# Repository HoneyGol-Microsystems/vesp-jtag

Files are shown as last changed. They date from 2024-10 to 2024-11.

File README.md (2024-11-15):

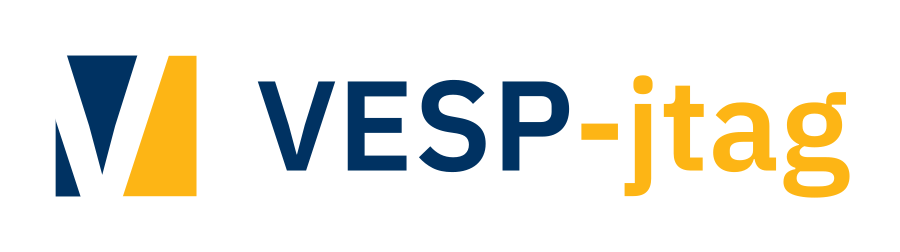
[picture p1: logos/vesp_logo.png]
vesp-jtag logo
# 
An Open Source Hardware JTAG/UART/GPIO interface board based on the amazing [Steppenprobe](https://github.com/diegoherranz/steppenprobe) containing Pmod-compatible connector.

## Basic specs:

- Open Source Hardware and designed in [KiCad](https://kicad.org).
- Majority of footprints have easy to solder 0805 packages.
- [FT2232H](https://ftdichip.com/products/ft2232hl)-based.
- Simultaneous operation of JTAG/UART or GPIO/UART (software-configurable).
- Standard Pmod connector for direct connection to a compatible FPGA.
- Signals also available on 2.54 mm pin header to work with any custom pinout.
- USB powered: no power supply needed.
- USB type-C receptacle: more convenient (reversible) and future-proof.
- 2 GPIO and 2 user-controllable LEDs.
- I/O buffers for protection and compatible with a wide voltage range (1.65 V to 5.5 V).
- Descriptive LED indicators.
- (TODO) OpenOCD compatibility.

*Please note that the board itself is wider than the Pmod standard allows, therefore it is not entirely "Pmod compatible". It may happen that if Pmod ports on your FPGA board are too close to each other, another Pmod board will not fit next to the vesp-jtag at the same time.*

## Schematic PDF, Gerbers and other generated files:
See [releases](https://github.com/HoneyGol-Microsystems/vesp-jtag/releases).

## FTDI channels

The FT2232H has 2 independent channels. In this board:

- Channel A: Used as a JTAG or GPIOs
- Channel B: Used as an UART.

After enumeration, both channels will default to the UART mode, so on a Linux system they will show up as `/dev/ttyUSB0` and `/dev/ttyUSB1`. When the channel A gets reconfigured to a MPSSE mode (e.g. when using OpenOCD with it), then `/dev/ttyUSB0` will disappear and the channel B will remain as `/dev/ttyUSB1`.

## 3D renders

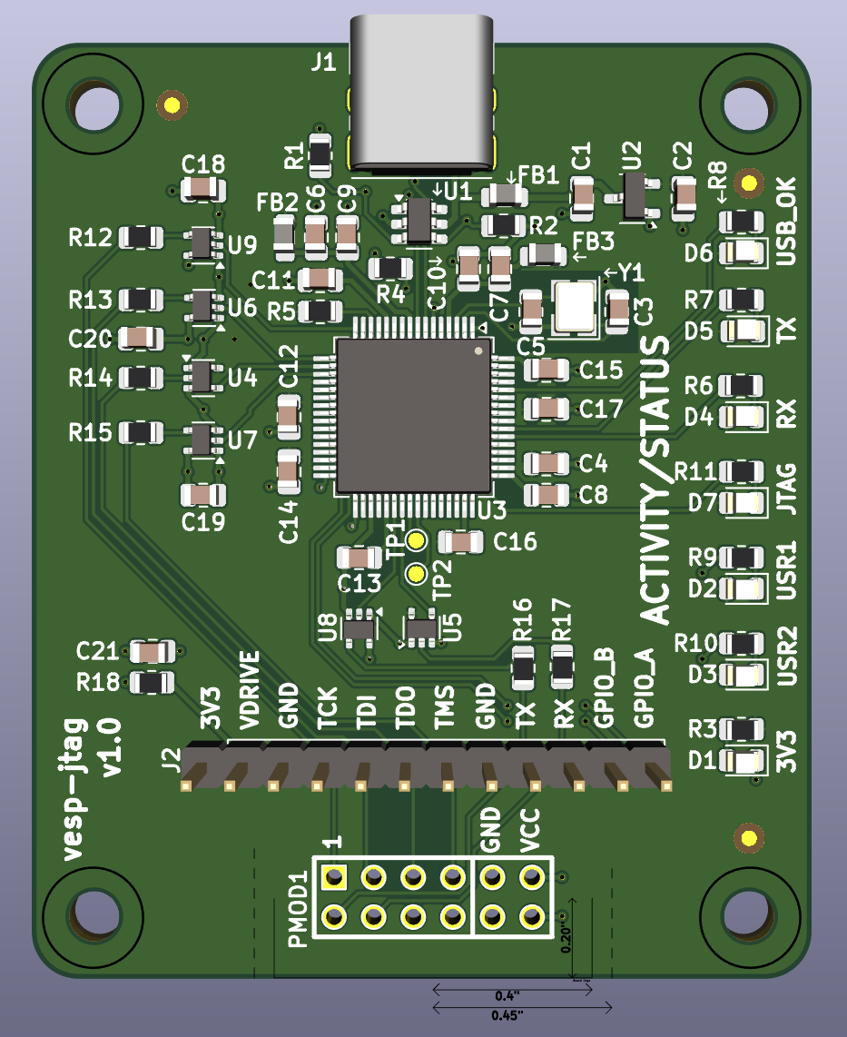
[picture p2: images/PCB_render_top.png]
PCB top view
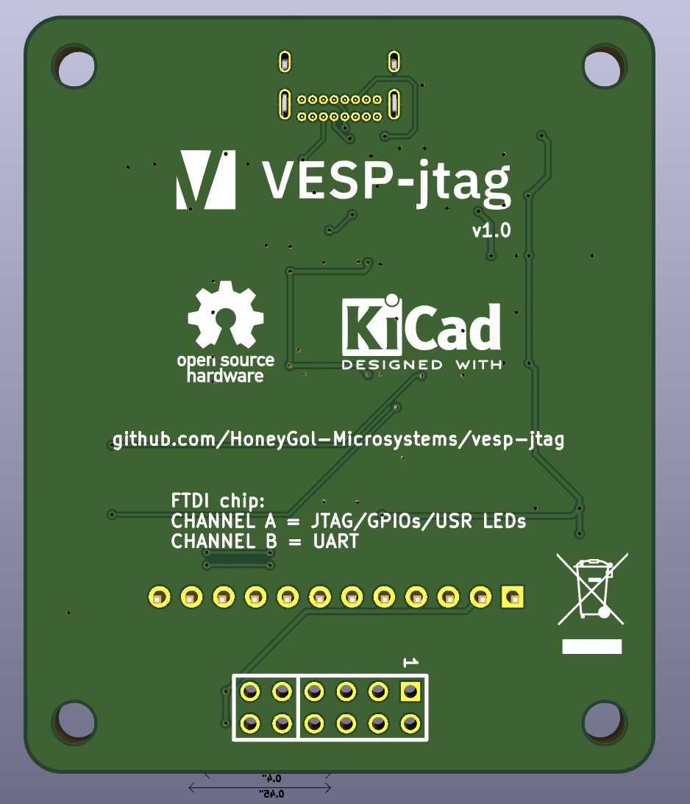
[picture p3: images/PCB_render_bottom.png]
PCB bottom view
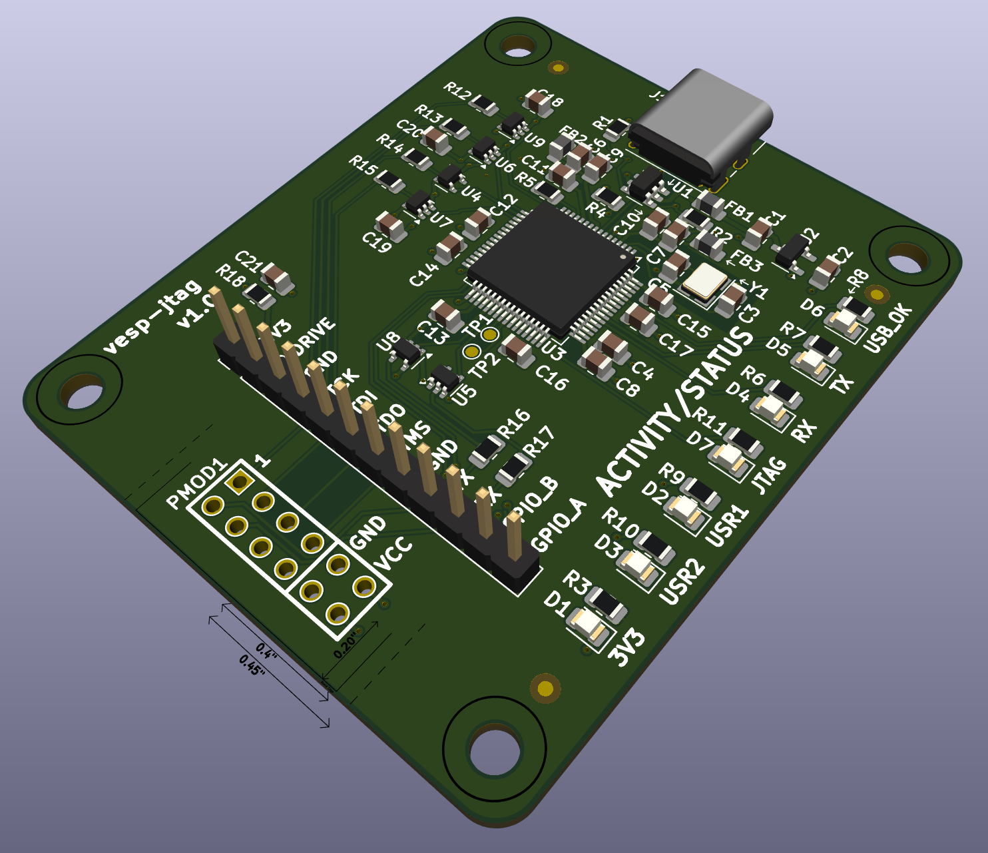
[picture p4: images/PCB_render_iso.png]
PCB isometric view
  

## OpenOCD example commands
TODO

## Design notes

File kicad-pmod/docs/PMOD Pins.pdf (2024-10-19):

PMod Interface | I2C Interface
Single Width PMod | Double Width PMod
Host | Edge | Peripheral 1 | 1 Host | 7 | Edge | Peripheral 1 7 | 1 | Edge
2 | | | 2 | 2 | 8 | | | 8 | 2 | 1 | 2 | SCL | SCL
3 | | | 3 | 3 | 9 | | | 9 | 3 | 3 | 4 | SDA | SDA
4 | | | 4 | 4 | 10 | | | 10 | 4 | 5 | 6 | GND | GND
5 | | | 5 | 5 | 11 | | | 11 | 5 | 7 | 8 | VCC | VCC
6 | | | 6 | 6 | 12 | | | 12 | 6
| 0.40" | 0.15" | | Top | Bot | 0.45" | 0.20" | Bot | Top

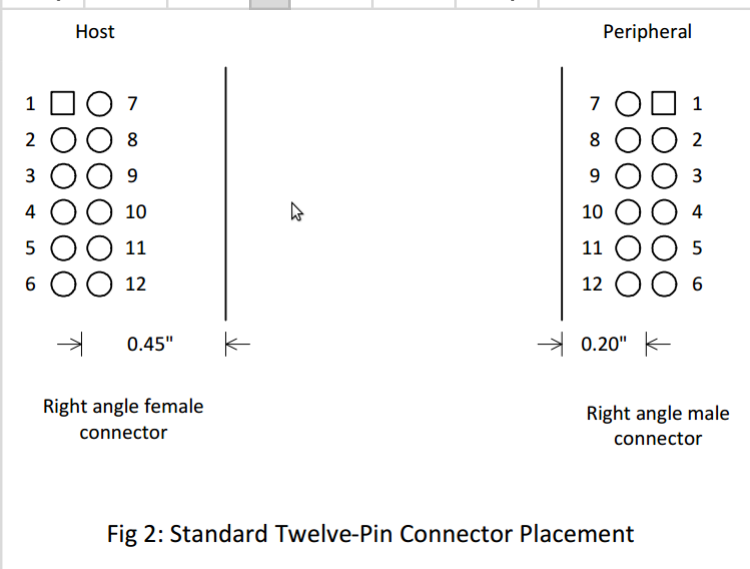
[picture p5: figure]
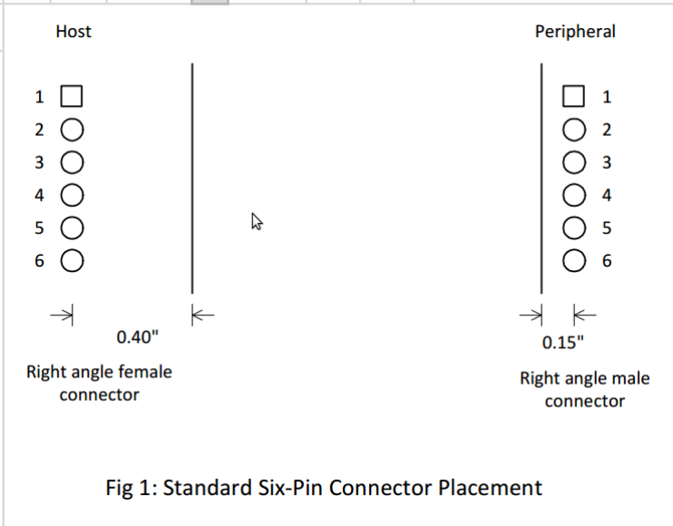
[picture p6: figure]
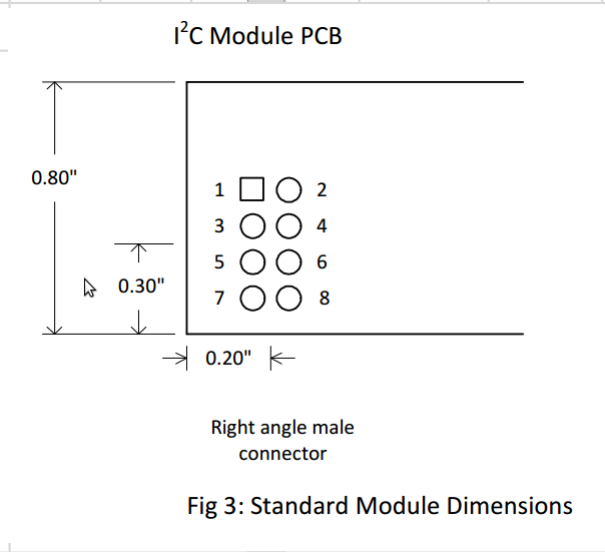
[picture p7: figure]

Pmod Pin | Standard Pin | | | Standard Pins | | Pmod Pins
1 | 2 | IO | Edge | 1 | 2 | Edge | 7 | 1
2 | 4 | IO | | 3 | 4 | | 8 | 2
3 | 6 | IO | | 5 | 6 | | 9 | 3
4 | 8 | IO | | 7 | 8 | | 10 | 4
5 | 10 | GND | | 9 | 10 | | 11 | 5
6 | 12 | VCC | | 11 | 12 | | 12 | 6
7 | 1 | IO
8 | 3 | IO
9 | 5 | IO
10 | 7 | IO
11 | 9 | GND
12 | 11 | VCC
Pmod Pin | Standard Pin | | | Standard Pins | | Pmod Pins
1 | 11 | IO | Edge | 12 | 11 | Edge | 7 | 1
2 | 9 | IO | | 10 | 9 | | 8 | 2
3 | 7 | IO | | 8 | 7 | | 9 | 3
4 | 5 | IO | | 6 | 5 | | 10 | 4
5 | 3 | GND | | 4 | 3 | | 11 | 5
6 | 1 | VCC | | 2 | 1 | | 12 | 6
7 | 12 | IO 8 | 10 | IO 9 | 8 | IO
10 | 6 | IO
11 | 4 | GND
12 | 2 | VCC

Type 1 GPIO | Type 1A Expanded GPIO | Type 2 SPI | Type 2A Expanded SPI | Type 3 UART | Type 4 UART | Type 4A Expanded UART | Type 5 H-Bridge | Type 6 Dual H-Bridge
1 2 3 4 | IO1 IO2 IO3 IO4 | In/Out In/Out In/Out In/Out | 1 2 3 4 | IOA1 IOA2 IOA3 IOA4 | In/Out In/Out In/Out In/Out | 1 2 3 4 | SS MOSI MISO SCK | Out Out | 1 2 | SS MOSI | Out Out | 1 2 | CTS RTS | Out | 1 | CTS | In | 1 | CTS | In | 1 DIR | Out | 1 DIR1 | Out
| | | | | | | | | | | | | | In | 2 | TXD | Out | 2 | TXD | Out | 2 EN | Out | 2 EN1 | Out
| | | | | | | | In | 3 | MISO | In | 3 | RXD | In | 3 | RXD | In | 3 | RXD | In | 3 SA | In | 3 DIR2 | Out
| | | | | | | | Out | 4 | SCK | Out | 4 | TXD | Out | 4 | RTS | Out | 4 | RTS | Out | 4 SB | In | 4 EN2 | Out
5 | GND | | 5 | GND | | 5 | GND | | 5 | GND | | 5 | GND | | 5 | GND | | 5 | GND | | 5 GND | | 5 GND
6 | VCC | | 6 | VCC | | 6 | VCC | | 6 | VCC | | 6 | VCC | | 6 | VCC | | 6 | VCC | | 6 VCC | | 6 VCC
| | | 7 8 9 10 | IOB1 IOB2 IOB3 IOB4 | In/Out In/Out In/Out In/Out | | | | 7 8 9 10 | INT RESET N/S N/S | In | | | | | | | 7 | INT | In
| | | | | | | | | | | Out | | | | | | | 8 | RESET | Out
| | | | | | | | | | | N/S N/S | | | | | | | 9 10 | N/S N/S | N/S N/S
| | | 11 | GND | | | | | 11 | GND | | | | | | | | 11 | GND
| | | 12 | VCC | | | | | 12 | VCC | | | | | | | | 12 | VCC
| | | | | | SS - Slave Select. Active low to enable slave device slave to master SCK - Serial clock. Data clock from master to slave | | | | | | CTS - Permission for peripheral to send data to host RTS - Request from peripheral to send data to host RXD - Data from peripheral to host | | | CTS - Device will only transmit when this signal is asserted RTS - Device is ready to receive data RXD - Data from peripheral to host TXD - Data from host to peripheral | | | CTS - Device will only transmit when this signal is asserted RTS - Device is ready to receive data RXD - Data from peripheral to host TXD - Data from host to peripheral INT - Interrupt signal from peripheral to host RESET - Reset signal for host to reset peripheral N/S - Not-specified depending on the module these pins may be unconnected or additional module specific inputs or outputs. | | | DIR - Motor direction EN - Motor enable, active high SA - feedback sense A SB - feedback sense B | | DIR1 - Motor/Phase 1 direction, active high MOSI - Master Out Slave In. Data from master to slave EN1 - Motor/Phase 1 enable MISO - Master In Slave Out. Data from DIR2 - Motor/Phase 2 direction, active high EN2 - Motor/Phase 2 enable
Pin | Signal | Direction | Pin | Signal | Direction | Pin | Signal | Direction | Pin | Signal | Direction | Pin | Signal | Direction | Pin | Signal | Direction | Pin | Signal | Direction | Pin | Signal | Direction | Pin | Signal | Direction

Pmod "High Speed" | XADC Pmod | Low Speed
Pin | Signal | LVDS Pair | Pin | Signal | LVDS Pair | Pin | Signal | LVDS Pair
1 | JA1_P | JA1 | 1 | JA1_P | JA1 | 1 | IO1 | NA
2 | JA1_N | | 2 | JA2_P | JA2 | 2 | IO2
3 | JA2_P | JA2 | 3 | JA3_P | JA3 | 3 | IO3
4 | JA2_N | | 4 | JA4_P | JA4 | 4 | IO4
5 | GND | | 5 | GND | | 5 | GND
6 | VCC | | 6 | VCC | | 6 | VCC
7 | JA3_P | JA3 | 7 | JA1_N | JA1 | 7 | IO1
| JA3_N | | 8 | JA2_N | JA2 | 8 | IO2 | NA 8
9 | JA4_P | JA4 | 9 | JA3_N | JA3 | 9 | IO3
10 | JA4_N | | 10 | JA4_N | JA4 | 10 | IO4
11 | GND | | 11 | GND | | 11 | GND
12 | VCC | | 12 | VCC | | 12 | VCC
* 0 Ohm series resistor * ESD protection | | | * No series resistor * ESD protection | | | * ~200 Ohm series resistor * Sometimes ESD protection
TMDS_33 input + output | ~XADC Pmod | | LVDS_25 input/output
LVDS_25 input | | Pin | Signal | LVDS Pair
1 | JA1_N | JA1
2 | JA2_N | JA2
3 | JA3_N | JA3
4 | JA4_N | JA4
5 | GND
6 | VCC
7 | JA1_P | JA1
8 | JA2_P | JA2
9 | JA3_P | JA3
10 | JA4_P | JA4
11 | GND
12 | VCC

Digilent Arty (https://reference.digilentinc.com/_media/arty:arty_sch.pdf) | Artix 7 | 100E
JA | Low Speed
| High Speed | Group 1 JB | No ESD?, JB1 - SRCC, JB2 - MRCC
JC | High Speed | | No ESD?
JD | Low Speed | | Uses mostly clock pins
Digilent Nexys Video (https://reference.digilentinc.com/_media/nexys-video:nexys_video_sch.pdf) | Artix 7 | GigE, HDMI In, HDMI Out, DP Out -- FMC(2 x HDMI In)
JA | Low Speed | Group 1
JB | High Speed | Group 2
JC | High Speed
JXADC XADC | | Group 3 | 100 Ohm Resistor
Digilent Nexys 4 DDR (https://reference.digilentinc.com/_media/nexys4-ddr:nexys_4_ddr_sch.pdf) | Artix 7
JA | Low Speed
JB | Low Speed
JC | Low Speed
JD | Low Speed
JXADC XADC
Digilent Genesys 2 (https://reference.digilentinc.com/_media/genesys2:genesys2_public_sch.pdf) | Kintex 7 | GigE, HDMI In, HDMI Out, DP In, DP Out, VGA Out -- FMC(2 x HDMI In)
JA | High Speed | Group 1
JB | High Speed
JC | Low Speed | Group 2
JD | Low Speed
JXADC XADC | | Group 3
Digilent Zybo (https://reference.digilentinc.com/_media/zybo:zybo_sch.pdf) | Zynq | GigE, HDMI BiDir, VGA Out
JA | XADC | Group 1
JB | High Speed
| High Speed | Group 2 JC
JD | High Speed | | JD3 - SRCC
JE | Low Speed
JF | Low Speed | Group 3 | MIO PMOD?
ZedBoard (https://reference.digilentinc.com/_media/reference/programmable-logic/zedboard/zedboard_sch.pdf) Zynq | | GigE, HDMI Out, VGA Out
JA1 | Low Speed | Group 1
JB1 | Low Speed

JC1 | High Speed | Group 2
JD1 | High Speed
JE1 | Low Speed | MIO PMOD?
Digilent PYNQ (https://reference.digilentinc.com/_media/reference/programmable-logic/pynq-z1/pynq-z1_sch.pdf) | Zynq | GigE, HDMI In, HDMI Out
PMODA | High Speed | Group 1 | 200 Ohm Resistor, JA3 - MRCC
PMODB | High Speed | | 200 Ohm Resistor
TOFE LowSpeedIO (https://github.com/timvideos/HDMI2USB-TOFE-LowSpeedIO/raw/master/docs/TOFE-LowSpeedIO-v1.0.0-4-g63ba16f.pdf) | | | Check Spacing
P2 | XADC | Group 1
P1 | XADC
P4 | Low Speed
P3 | Low Speed | Group 2
Numato Mimas V2 (https://docs.numato.com/wp-content/uploads/2016/08/MimasV2Sch.pdf) | Spartan 6 | | Check Spacing
P6 | ~XADC
P7 | ~XADC
P8 | ~XADC
P9 | ~XADC
Numato Waxwing (https://docs.numato.com/wp-content/uploads/2016/08/WaxwingBasicDevelopmentBoardSch.pdf) | Spartan 6 | | Check Spacing
P3 | XADC
P5 | XADC
P4 | XADC
MicroZed (http://zedboard.org/sites/default/files/documentations/MicroZed_Rev_F_Schematic_141212.pdf) | Zynq
J5 | | | MIO PMOD???

MyIRTech Z-turn with IO CapeZynq XADC?
PMOD1?
PMOD2?
PMOD3?
Pipistrello (http://www.saanlima.com/download/pipistrello-v2.0/pipistrello_v2_schematic.pdf) | Spartan 6
PMOD | Low Speed | | No resistors or ESD
icoBoard (http://downloads.amescon.com/icoboard.pdf) | Lattice??
P1 | Low Speed | | Check
P3 | Low Speed | | Check

P2 | Low Speed | Check
P4 | Low Speed | Check

| Numato | | | Numato | | | Numato | | | Numato | | | Numato | | | Digilent
HDMI Transmitter
Expansion Module

RTL8211E Gigabit Ethernet
Expansion Module | FT234 Expansion Module | VGA Display Expansion Module | Micro SD Expansion Module | Pmod SD: Full-sized SD Card Slot
http://numato.com/hdmi-transmitter-expansion-module/ http://numato.com/rtl8211e-gigabit-ethernet-expansion-module/ http://numato.com/ft234-expansion-module/ | http://numato.com/vga-display-expansion-module/ | http://numato.com/micro-sd-expansion-module/http://store.digilentinc.com/pmod-sd-full-sized-sd-card-slot/
2 x Dual PMOD | 3 x Dual PMOD | 1 x Dual PMOD | 2 x Dual PMOD | 1 x Dual PMOD | 1 x Dual PMOD
Module | ~XADC | P1 | Module | Low Speed | P1 | Module | Low Speed | P1 | Module | Low Speed | P1 | Module | Low Speed | P1 | Module | Low Speed | P1
PMod
Pin | Signal | Numato
| | Pin | PMod
| | | Pin | Signal | Numato
| | | | | Pin | PMod
| | | | | | Pin | Signal | Numato
| | | | | | | | Pin | PMod
| | | | | | | | | Pin | Signal | Numato
| | | | | | | | | | | Pin | PMod
| | | | | | | | | | | | Pin | Signal | Numato
| | | | | | | | | | | | | | Pin | PMod
| | | | | | | | | | | | | | | Pin | Signal | Direction
1 2 3 4 5 6 7 8 9 10 11 12 Module PMod Pin | TMDS-TX-2_P TMDS-TX-1_P TMDS-TX-0_P TMDS-TX-CLK_P GND VCC TMDS-TX-2_N TMDS-TX-1_N TMDS-TX-0_N TMDS-TX-CLK_N GND VCC Low Speed Signal | 2 4 6 8 10 12 1 3 5 7 9 11 P2 Numato Pin | 1 2 3 4 5 6 7 8 9 10 11 12 Module PMod Pin | NC ETH_RXCTL ETH_RXD1 ETH_RXD3 GND VCC NC ETH_RXD0 ETH_RXD2 ETH_INT_B GND VCC Low Speed Signal | 2 4 6 8 10 12 1 3 5 7 9 11 P2 Numato Pin | 1 2 3 4 5 6 7 8 9 10 11 12 | CBUS0 NC NC NC GND VCC TXD RTS RXD CTS GND VCC | 2 4 6 8 10 12 1 3 5 7 9 11 | 1 R1 2 2 G2 4 3 G1 6 4 B1 8 5 GND 10 6 VCC 12 7 R2 1 8 R0 3 9 G0 5 10 B0 7 11 GND 9 12 VCC 11 Module Low Speed P2 PMod Numato Pin Signal Pin | 1 DAT2 2 2 CMD 4 3 DAT0 6 4 NC 8 5 GND 10 6 VCC 12 7 DAT3 1 8 CLK 3 9 DAT1 5 10 NC 7 11 GND 9 12 VCC 11 | 1 SS Out 2 MOSI Out 3 MISO In 4 SCK Out 5 GND 6 VCC 7 DAT1 8 DAT2 9 CD 10 WP 11 GND 12 VCC
1 2 3 4 5 6 7 8 9 10 11 12 | TMDS-TX-SCL TMDS-TX-HOT NC NC GND VCC TMDS-TX-CEC TMDS-TX-SDA NC NC GND VCC | 2 4 6 8 10 12 1 3 5 7 9 11 | 1 2 3 4 5 6 7 8 9 10 11 12 Module PMod Pin | NC ETH_TXCLK ETH_TXD1 ETH_TXD3 GND VCC NC ETH_RXCLK ETH_TXD0 ETH_TXD2 GND VCC Low Speed Signal | 2 4 6 8 10 12 1 3 5 7 9 11 P3 Numato Pin | | | | 1 Vsync 2 2 NC 4 3 NC 6 4 NC 8 5 GND 10 6 VCC 12 7 Hsync 1 8 NC 3 9 NC 5 10 NC 7 11 GND 9 12 VCC 11
1 | ETH_RESET_B | 2
2 | ETH_MDIO | 4
3 | MAC_SDA | 6
4 | FPGA_CLK | 8
5 | GND | 10
6 | VCC | 12
7 | ETH_TXCTL | 1
8 | ETH_MDC | 3
9 | MAC_SCL | 5
10 | SYSCLK | 7
11 | GND | 9
12 | VCC | 11

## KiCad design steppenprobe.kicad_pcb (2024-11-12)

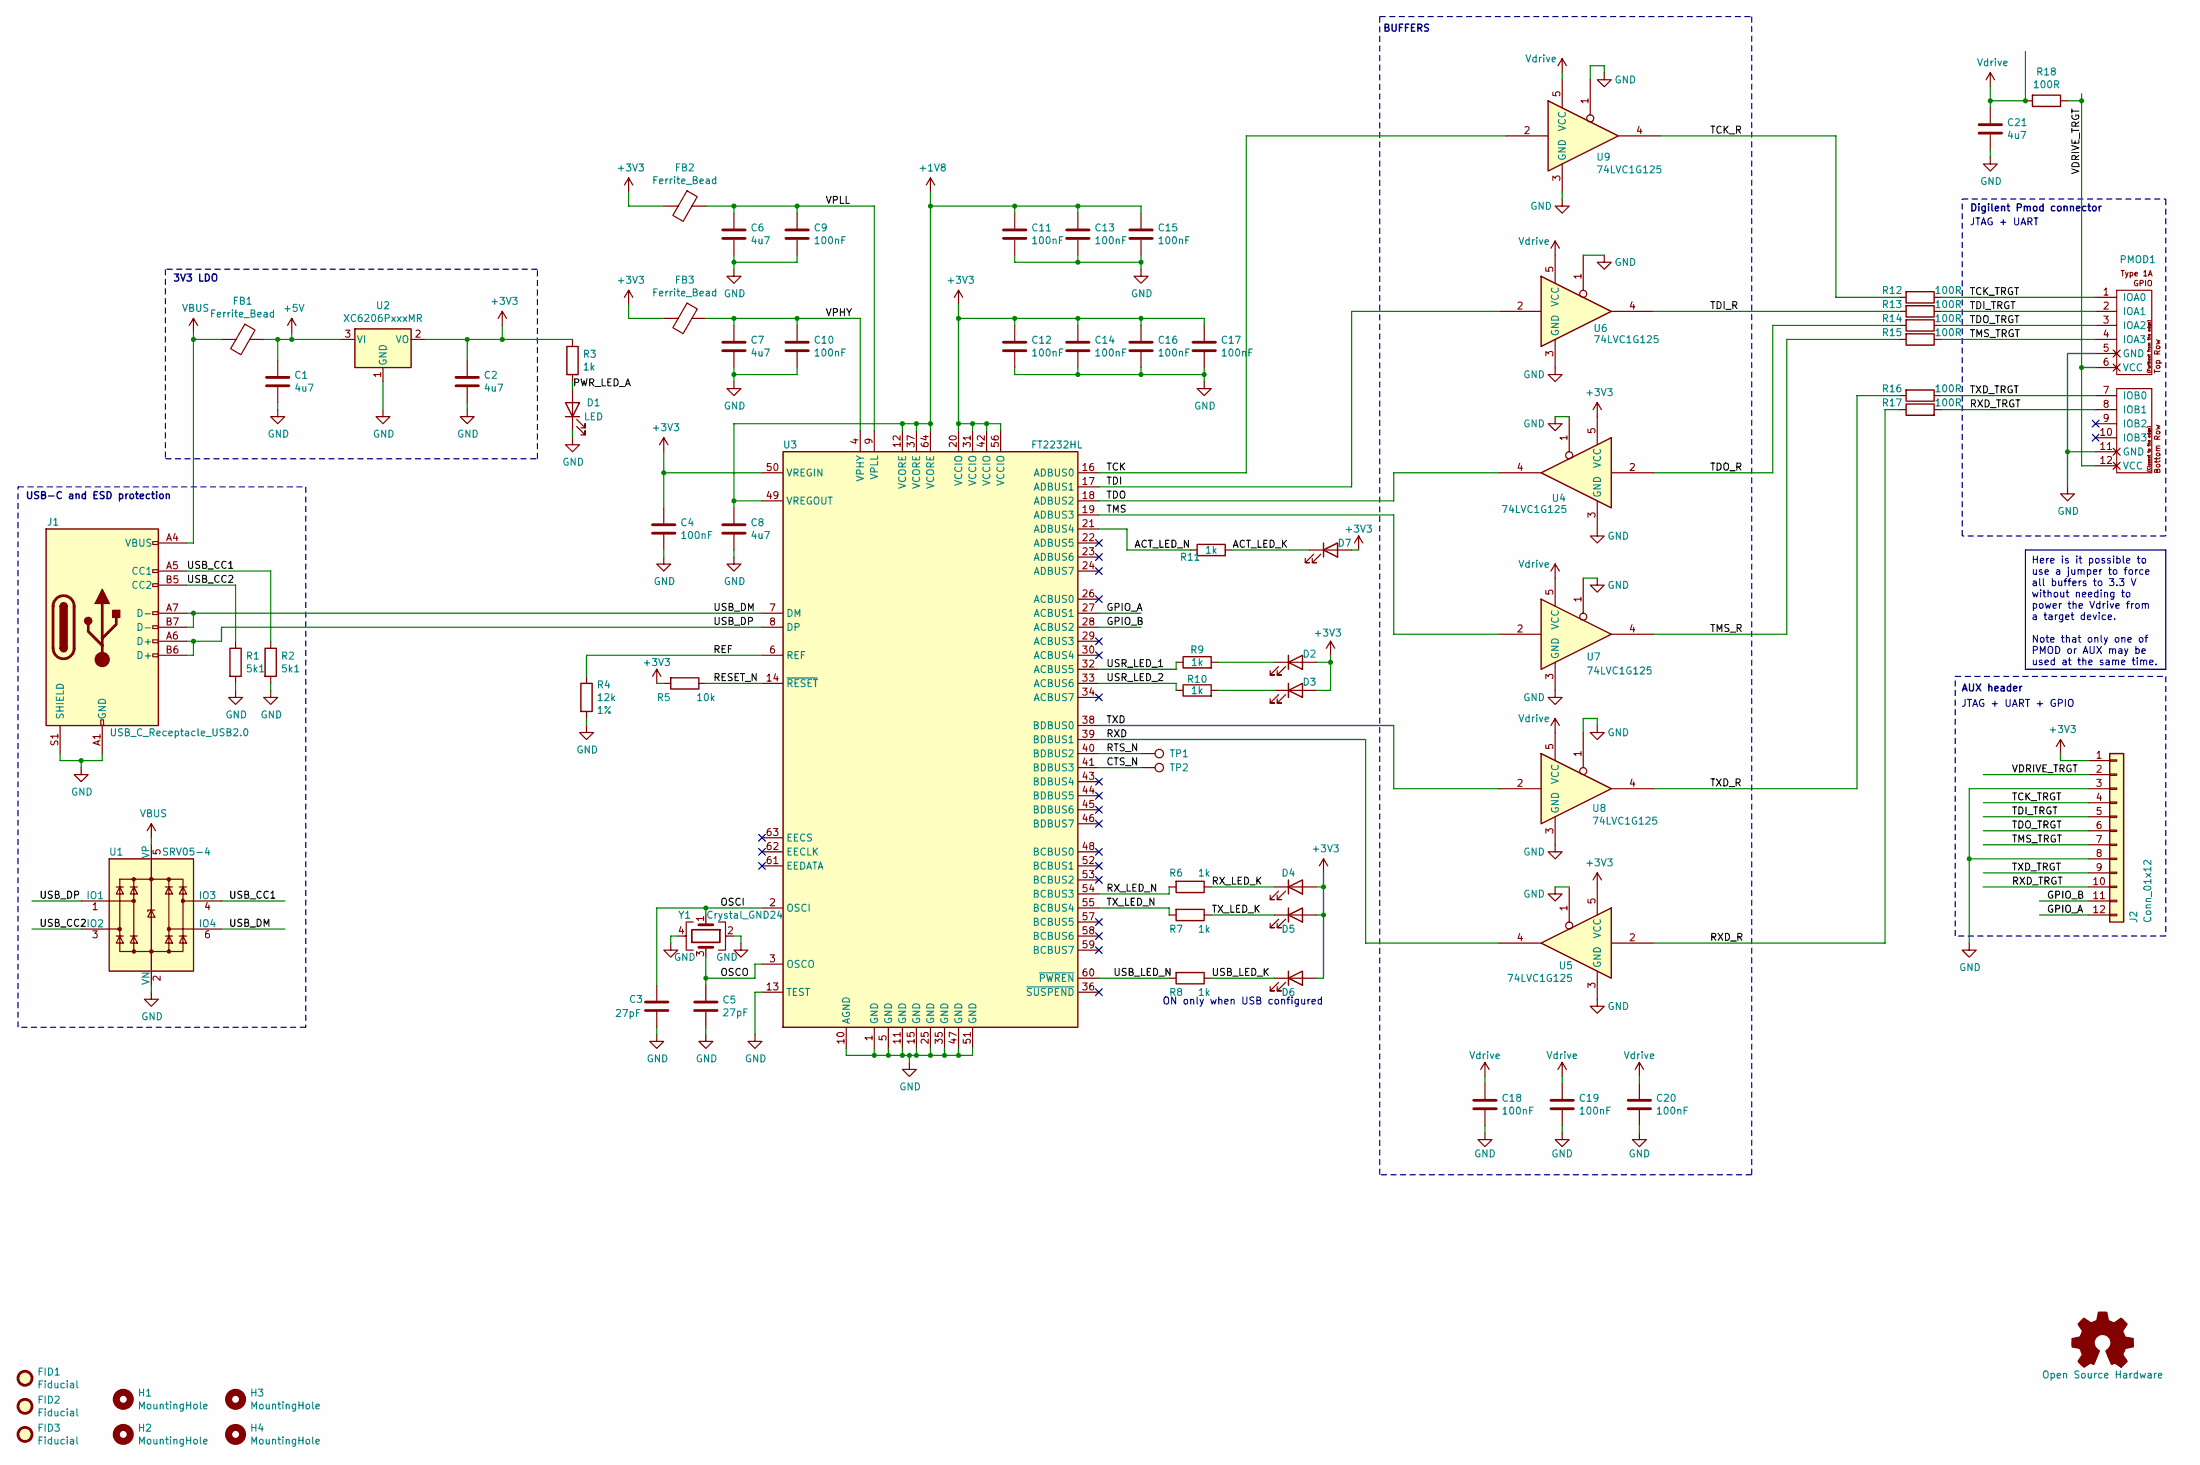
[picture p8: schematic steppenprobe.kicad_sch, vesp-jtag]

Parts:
C1, C2, C6, C7, C8, C21: 4u7; C_0805_2012Metric; Tolerance 10%; MPN CL10A475KO8NNNC; LCSC_PN C19666
C3, C5: 27pF; C_0805_2012Metric; Tolerance 5%; MPN C0603C270J5GAC; LCSC_PN C1656
C4, C9, C10, C11, C12, C13, C14, C15, C16, C17, C18, C19, C20: 100nF; C_0805_2012Metric; Tolerance 10%; MPN CC0603KRX7R9BB104; LCSC_PN C14663
D1, D4, D5, D6, D7: LED; LED_0805_2012Metric; MPN 19-217/GHC-YR1S2/3T; LCSC_PN C72043
D2, D3: LED; LED_0805_2012Metric
FB1, FB2, FB3: Ferrite_Bead; L_0805_2012Metric; MPN2 BKP1608HS121-T; LCSC_PN C85831
FID1, FID2, FID3: Fiducial; Fiducial_1mm_Mask2mm
H1, H2, H3, H4: MountingHole; MountingHole_3.2mm_M3
J1: USB_C_Receptacle_USB2.0; USB_C_Receptacle_GCT_USB4085; MPN USB4085-GF-A
J2: Conn_01x12; PinHeader_1x12_P2.54mm_Vertical
LOGO1: Open Source Hardware; OSHW-Logo_7.5x8mm_SilkScreen
PMOD1: PMOD-Device-x2-Type-1A-GPIO; pmod_pin_array_6x2
R1, R2: 5k1; R_0805_2012Metric; Tolerance 5%; LCSC_PN C23186
R3, R6, R7, R8, R11: 1k; R_0805_2012Metric; Tolerance 5%; LCSC_PN C21190
R4: 12k; R_0805_2012Metric; Tolerance 1%; LCSC_PN C22790
R5: 10k; R_0805_2012Metric; Tolerance 5%; LCSC_PN C25804
R9, R10: 1k; R_0805_2012Metric
R12, R13, R14, R15, R16, R17, R18: 100R; R_0805_2012Metric; Tolerance 5%; LCSC_PN C22775
TP1, TP2: TestPoint; TestPoint_Pad_D1.0mm
U1: SRV05-4; SOT-23-6; MPN2 SRV05-4-P-T7; LCSC_PN C85364
U2: XC6206PxxxMR; SOT-23-3; MPN XC6206P332MR; LCSC_PN C5446
U3: FT2232HL; LQFP-64_10x10mm_P0.5mm; MPN FT2232HL; LCSC_PN C27882
U4, U5, U6, U7, U8, U9: 74LVC1G125; SOT-353_SC-70-5; MPN 74LVC1G125GW,125; LCSC_PN C12519
Y1: Crystal_GND24; Crystal_SMD_3225-4Pin_3.2x2.5mm; Tolerance 10PPM; MPN ABM8-12.000MHZ-20-B1U-T; LCSC_PN C9002

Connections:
+1V8: C8.1, C11.1, C13.1, C15.1, U3.12 (VCORE), U3.37 (VCORE), U3.49 (VREGOUT), U3.64 (VCORE)
+3V3: C2.1, C4.1, C12.1, C14.1, C16.1, C17.1, D2.2 (A), D3.2 (A), D4.2 (A), D5.2 (A), D6.2 (A), D7.2 (A), FB2.2, FB3.2, J2.1, R3.1, R5.2, U2.2 (VO), U3.20 (VCCIO), U3.31 (VCCIO), U3.42 (VCCIO), U3.50 (VREGIN), U3.56 (VCCIO), U4.5 (VCC), U5.5 (VCC)
+5V: C1.1, FB1.1, U2.3 (VI)
/ACT_LED_K: D7.1 (K), R11.2
/ACT_LED_N: R11.1, U3.21 (ADBUS4)
/CTS_N: TP2.1, U3.41 (BDBUS3)
/GPIO_A: J2.12, U3.27 (ACBUS1)
/GPIO_B: J2.11, U3.28 (ACBUS2)
/OSCI: C3.1, U3.2 (OSCI), Y1.1
/OSCO: C5.1, U3.3 (OSCO), Y1.3
/PWR_LED_A: D1.2 (A), R3.2
/REF: R4.1, U3.6 (REF)
/RESET_N: R5.1, U3.14 (~RESET)
/RTS_N: TP1.1, U3.40 (BDBUS2)
/RXD: U3.39 (BDBUS1), U5.4
/RXD_R: R17.1, U5.2
/RXD_TRGT: J2.10, PMOD1.8 (IOB1), R17.2
/RX_LED_K: D4.1 (K), R6.1
/RX_LED_N: R6.2, U3.54 (BCBUS3)
/TCK: U3.16 (ADBUS0), U9.2
/TCK_R: R12.2, U9.4
/TCK_TRGT: J2.4, PMOD1.1 (IOA0), R12.1
/TDI: U3.17 (ADBUS1), U6.2
/TDI_R: R13.2, U6.4
/TDI_TRGT: J2.5, PMOD1.2 (IOA1), R13.1
/TDO: U3.18 (ADBUS2), U4.4
/TDO_R: R14.2, U4.2
/TDO_TRGT: J2.6, PMOD1.3 (IOA2), R14.1
/TMS: U3.19 (ADBUS3), U7.2
/TMS_R: R15.2, U7.4
/TMS_TRGT: J2.7, PMOD1.4 (IOA3), R15.1
/TXD: U3.38 (BDBUS0), U8.2
/TXD_R: R16.2, U8.4
/TXD_TRGT: J2.9, PMOD1.7 (IOB0), R16.1
/TX_LED_K: D5.1 (K), R7.1
/TX_LED_N: R7.2, U3.55 (BCBUS4)
/USB_CC1: J1.A5 (CC1), R2.1, U1.4 (IO3)
/USB_CC2: J1.B5 (CC2), R1.1, U1.3 (IO2)
/USB_DM: J1.A7 (D-), J1.B7 (D-), U1.6 (IO4), U3.7 (DM)
/USB_DP: J1.A6 (D+), J1.B6 (D+), U1.1 (IO1), U3.8 (DP)
/USB_LED_K: D6.1 (K), R8.1
/USB_LED_N: R8.2, U3.60 (~PWREN)
/USR_LED_1: R9.1, U3.32 (ACBUS5)
/USR_LED_2: R10.1, U3.33 (ACBUS6)
/VDRIVE_TRGT: J2.2, PMOD1.6 (VCC), PMOD1.12 (VCC), R18.1
/VPHY: C7.1, C10.1, FB3.1, U3.4 (VPHY)
/VPLL: C6.1, C9.1, FB2.1, U3.9 (VPLL)
GND: C1.2, C2.2, C3.2, C4.2, C5.2, C6.2, C7.2, C8.2, C9.2, C10.2, C11.2, C12.2, C13.2, C14.2, C15.2, C16.2, C17.2, C18.2, C19.2, C20.2, C21.2, D1.1 (K), J1.A1 (GND), J1.A12 (GND), J1.B1 (GND), J1.B12 (GND), J1.S1 (SHIELD), J2.3, J2.8, PMOD1.5 (GND), PMOD1.11 (GND), R1.2, R2.2, R4.2, U1.2 (VN), U2.1 (GND), U3.1 (GND), U3.5 (GND), U3.10 (AGND), U3.11 (GND), U3.13 (TEST), U3.15 (GND), U3.25 (GND), U3.35 (GND), U3.47 (GND), U3.51 (GND), U4.1, U4.3 (GND), U5.1, U5.3 (GND), U6.1, U6.3 (GND), U7.1, U7.3 (GND), U8.1, U8.3 (GND), U9.1, U9.3 (GND), Y1.2, Y1.4
unnamed: D2.1 (K), R9.2
unnamed: D3.1 (K), R10.2
VBUS: FB1.2, J1.A4 (VBUS), J1.A9 (VBUS), J1.B4 (VBUS), J1.B9 (VBUS), U1.5 (VP)
Vdrive: C18.1, C19.1, C20.1, C21.1, R18.2, U6.5 (VCC), U7.5 (VCC), U8.5 (VCC), U9.5 (VCC)

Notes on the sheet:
Here is it possible to use a jumper to force all buffers to 3.3 V without needing to power the Vdrive from a target device. Note that only one of PMOD or AUX may be used at the same time.
ON only when USB configured
JTAG + UART
3V3 LDO
AUX header
JTAG + UART + GPIO
Digilent Pmod connector
USB-C and ESD protection
BUFFERS

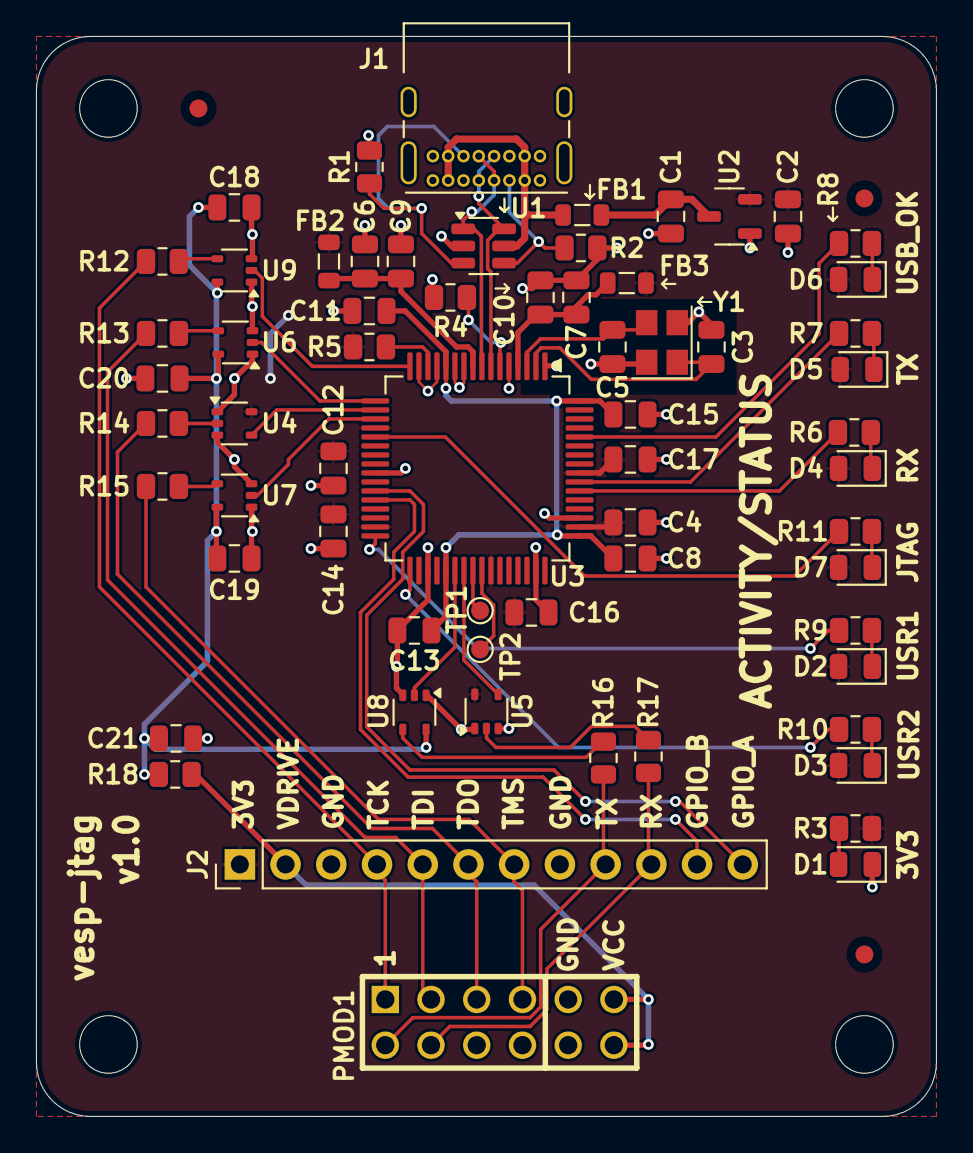
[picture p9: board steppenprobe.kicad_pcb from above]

Board: 2 copper layers, 50.0 x 60.0 mm, 72 parts (1 on the bottom side), 52 nets.

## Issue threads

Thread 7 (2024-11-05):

Osc

andreondra, 2024-11-05:
- remove keepout from GND plane and fill
- flip caps
- remove guard ring
- 3v3 keepout can be kept

Closed 2024-11-06.

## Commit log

2024-10-19 Removed EEPROM.
    [steppenprobe.kicad_sch]
2024-10-19 Added PMOD.
    [steppenprobe.kicad_sch]
2024-10-21 Added user leds, removed uneccessary connections.
    [steppenprobe.kicad_sch]
2024-10-22 Fixed errors, assigned footprints.
    [steppenprobe.kicad_pcb, steppenprobe.kicad_sch]
2024-11-02 Updated footprints, removed testpoints, edited PCB layout.
    [steppenprobe.kicad_pcb, steppenprobe.kicad_sch]
2024-11-03 Updated pcb.
    [steppenprobe.kicad_pcb]
2024-11-04 Rotated 3V3 LED.
    [steppenprobe.kicad_pcb]
2024-11-04 Synced footprints.
    [steppenprobe.kicad_pcb, steppenprobe.kicad_sch]
2024-11-04 Fixed part numbering.
    [steppenprobe.kicad_pcb, steppenprobe.kicad_sch]
2024-11-04 Edited silkscreen graphics.
    [steppenprobe.kicad_pcb]
2024-11-04 Fixed DRC problems, added logo dir.
    [steppenprobe.kicad_pcb]
2024-11-05 Reworked oscillator placement. Fixed silkscreen, added arrows.
    [steppenprobe.kicad_pcb]
2024-11-05 Moved vias closer to pads.
    [steppenprobe.kicad_pcb]
2024-11-06 Moved vias, silkscreen alignment.
    [steppenprobe.kicad_pcb]
2024-11-12 Changed export settings.
    [steppenprobe.kicad_pcb]
2024-11-15 Updated part numbers.
    [steppenprobe.kicad_sch]
2024-12-03 OpenOCD config initial commit.
    [vesp-jtag.cfg]
